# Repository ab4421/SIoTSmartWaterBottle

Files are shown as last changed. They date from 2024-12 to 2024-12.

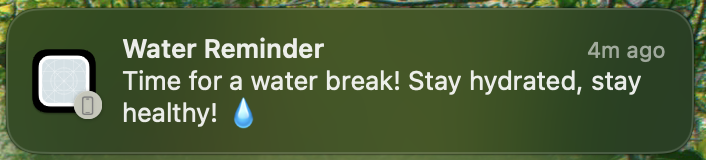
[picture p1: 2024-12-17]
AppFiles/AppScreenshots/WaterReminderNotification.png

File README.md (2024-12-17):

# Retrofit IoT Water Bottle Tracker

This repository contains the code and documentation for a compact, retrofit IoT device that transforms any conventional water bottle into a smart hydration tracker. By integrating a load cell, IMU, BLE communication, and HealthKit APIs, this system dynamically measures water volume, correlates intake with exercise data, and provides personalised daily hydration goals and reminders.

## License and Contributions
This project is licensed under the [Creative Commons Attribution-NonCommercial 4.0 International (CC BY-NC 4.0)](https://creativecommons.org/licenses/by-nc/4.0/) license.

**Key points:**
- **Attribution Required:** You must give appropriate credit to the original author(s) and clearly indicate any changes made.
- **Non-Commercial:** You may not use the material for commercial purposes.
- **No Additional Restrictions:** You may not apply legal terms or technological measures that legally restrict others from doing anything the license permits.

Contributions are welcome! Feel free to open issues, suggest features, or submit pull requests. 

**Acknowledgement:** Large Language Models (LLMs) such as ChatGPT (GPT-4), Sonnet 3.5, and related tools were used to assist with syntax, code snippet generation, and refining implementations. These tools helped streamline development, clarify code logic, and improve documentation quality.

## Key Features

- **External Sensing for Water Volume:**  
  Attaches to any bottle’s base. A load cell sensor and calibration logic convert weight into volume (1 g ≈ 1 mL).
  
- **IMU-Based Stability Checks:**  
  Uses an onboard 6-axis IMU to ensure accurate measurements only when the bottle is upright and stable.
  
- **BLE Connectivity:**  
  Communicates with an iOS application in real-time via Bluetooth Low Energy. Sensor data, state machine updates, and commands are all exchanged wirelessly.

- **HealthKit Integration:**  
  Dynamically adjusts daily hydration goals based on the user’s personal health metrics (height, weight, age) and exercise time sourced from Apple Watch via HealthKit.

- **User-Centred UI/UX:**  
  The accompanying iOS app displays daily intake progress, water levels, and allows manual entry of off-bottle consumption. Day/week data views and statistical insights help users understand and improve their hydration habits.

- **Actuation and Interventions:**  
  Sends notifications if no water intake is logged within an hour, prompting the user to drink or refill. On-board LED indicators reflect device states and assist in debugging.

## Repository Structure

- **/Arduino**  
  Contains Arduino/C++ source code for the SeeedStudio XIAO nrf52840 Sense board. This includes:
  - Load cell sensor calibration and reading code.
  - IMU data collection and stability logic.
  - BLE services and characteristics for data transmission.
  - State machine logic for IDLE → AWAKE → ACTIVE → REFILL states.
 - The final final code for the entire project is in BottleHousingv1.ino

- **/AppFiles**  
  Swift/SwiftUI code for the iOS application:
  - BLEManager implementation for scanning, connecting, and receiving data from the device.
  - Views for daily/weekly intake data, goal calculation, and user interactions.
  - Integration with HealthKit to fetch activity and body metrics.
  - Notification scheduling for hydration reminders.

- **/Housing**  
  CAD files and STL models of the custom 3D-printed housing designed to fit the sensor assembly onto various bottles.

- **/RawSensorDataPlots**  
  Sample CSV data (IMU and scale readings), calibration logs, and scripts/notebooks for offline data analysis and plotting.

- **/AppFiles/AppScreenshots**  
  All screenshots of app features and screens. 

## Getting Started

1. **Hardware Setup:**
   - Assemble the load cell (MUS) and connect it to the XIAO Sense board as per the wiring diagrams.
   - Modify the housing onto your chosen bottle, ensuring minimal interference and stable contact.
   
2. **Firmware Upload:**
   - Install the Arduino IDE and required board packages.
   - Open `ArduinoSketches/BottleHousingv1` in Arduino IDE.
   - Update any BLE UUIDs, gap values, or thresholds if needed.
   - Upload the code to the XIAO nrf52840 Sense board.

3. **iOS App Setup:**
   - Open `AppFiles/SmartWaterTracker` project in Xcode.
   - Connect an iOS device with BLE and HealthKit access.
   - Build and run the app on your device.
   - Grant necessary HealthKit permissions and pair with the IoT device.

4. **Calibration and Tuning:**
   - Use the app’s calibration function (tare) to set the empty bottle weight.
   - Perform test readings and compare to known reference weights to fine-tune the gap value if necessary.

## Dependencies and Requirements

- **Hardware:**
  - SeeedStudio XIAO nrf52840 Sense microcontroller.
  - M5Stack mini unit scale (MUS) or compatible load cell assembly.
  - BLE-compatible iOS device (iPhone/iPad running iOS 14+).
  
- **Software:**
  - Arduino IDE (v1.8.13 or newer).
  - Xcode (for iOS development).
  - Swift 5.0+ and iOS 14+ SDK.
  - HealthKit and Core Bluetooth frameworks.

## Contact and Support

For questions, issues, or support, please contact [ab4421@ic.ac.uk] or open an issue in this repository.

---
**Stay Hydrated!** This project aims to encourage healthier habits through unobtrusive IoT interventions and personalised guidance.

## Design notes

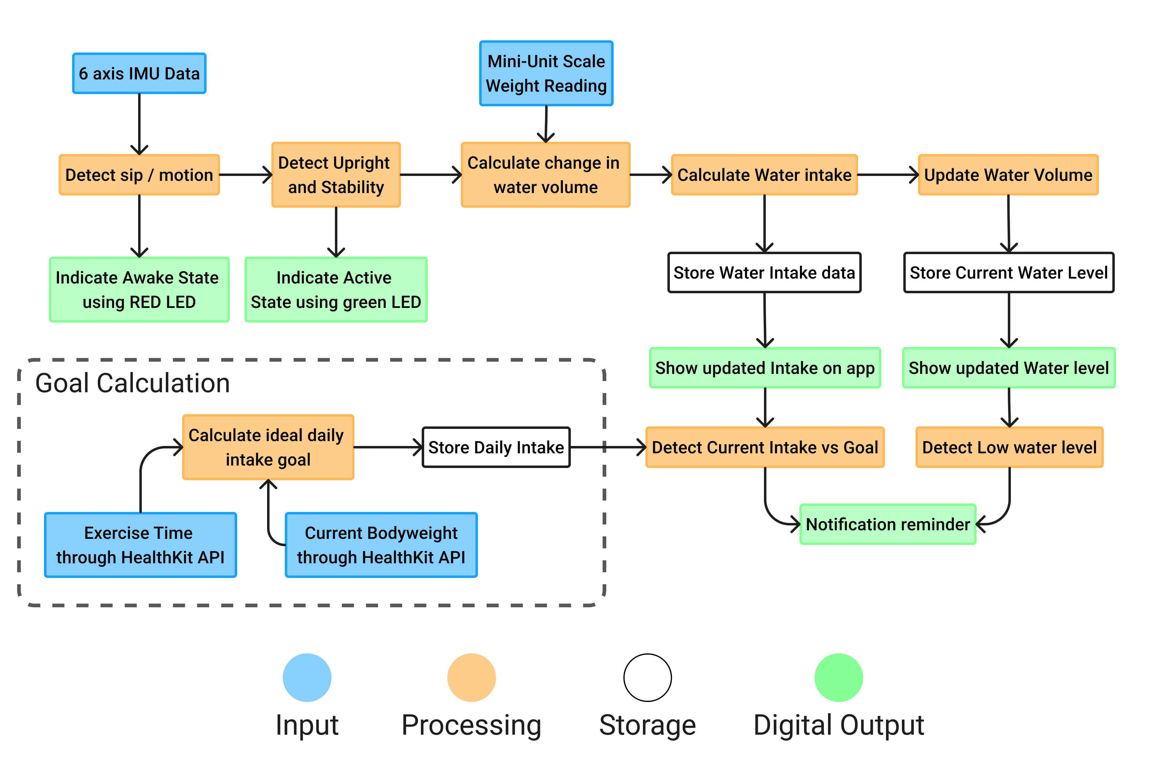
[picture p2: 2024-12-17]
SystemDiagram.png

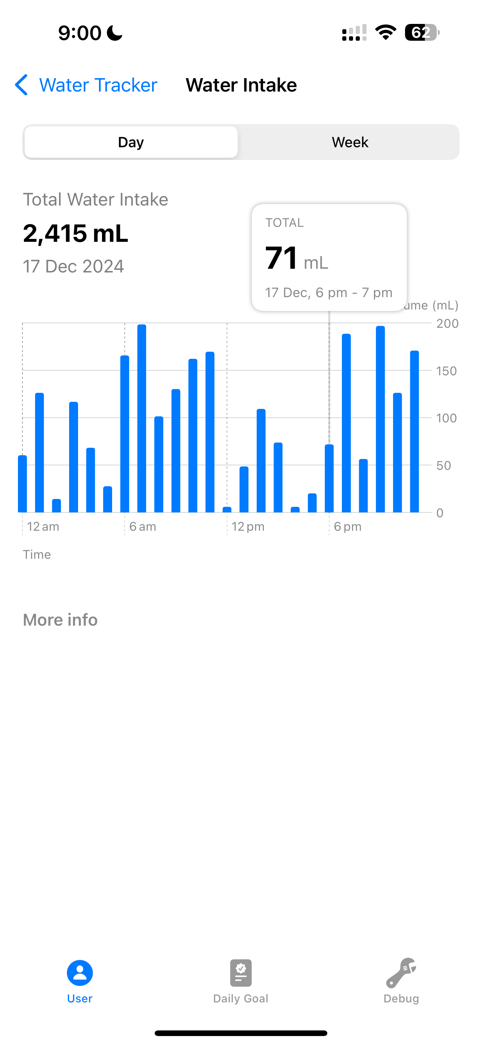
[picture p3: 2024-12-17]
AppFiles/AppScreenshots/DataViewDaily.PNG

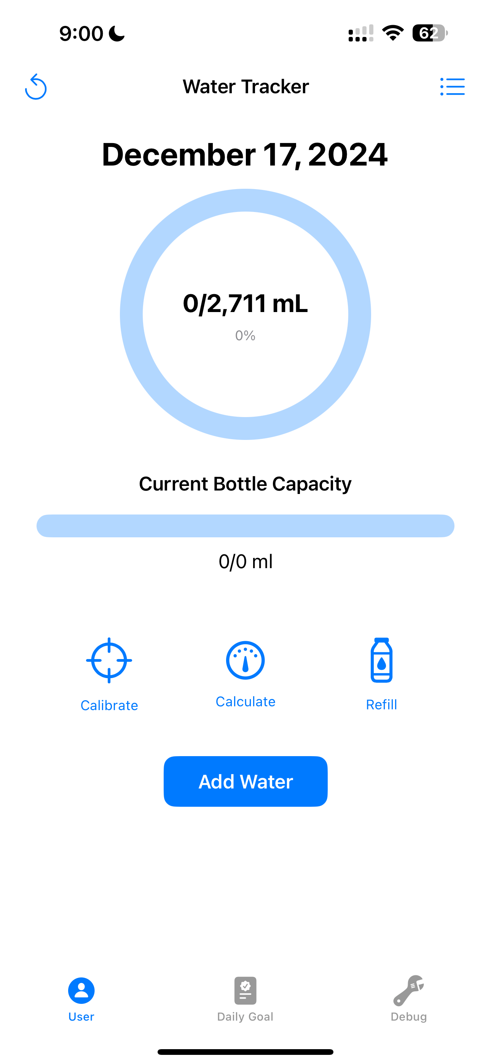
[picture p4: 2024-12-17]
AppFiles/AppScreenshots/UserView.PNG

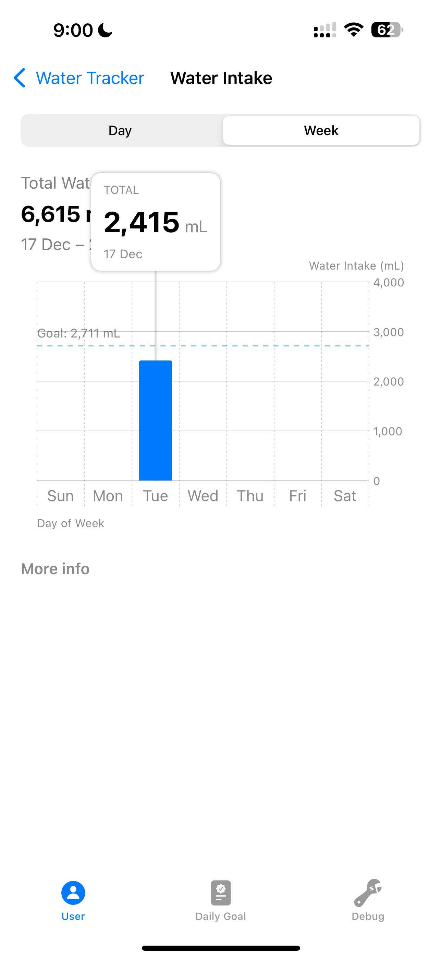
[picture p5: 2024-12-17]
AppFiles/AppScreenshots/DataViewWeekly.PNG

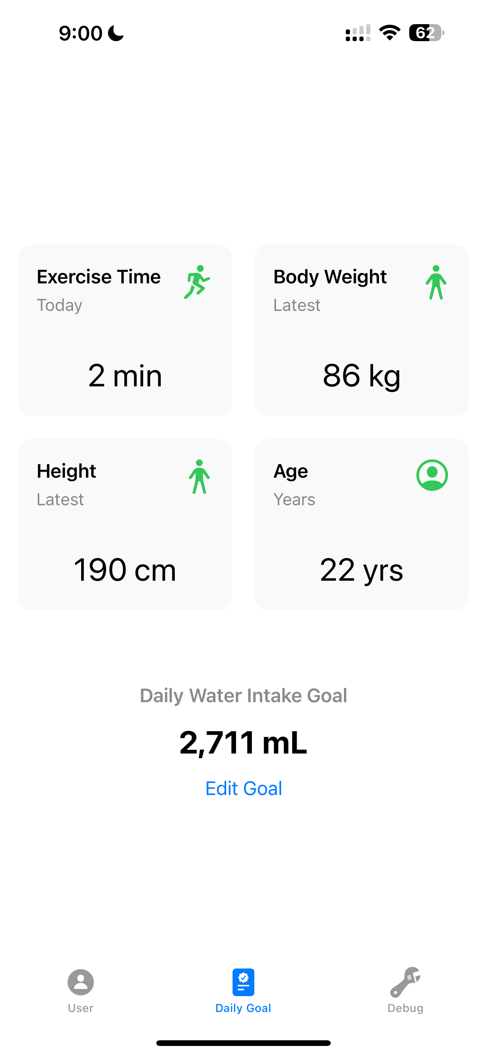
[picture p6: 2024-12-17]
AppFiles/AppScreenshots/GoalView.PNG

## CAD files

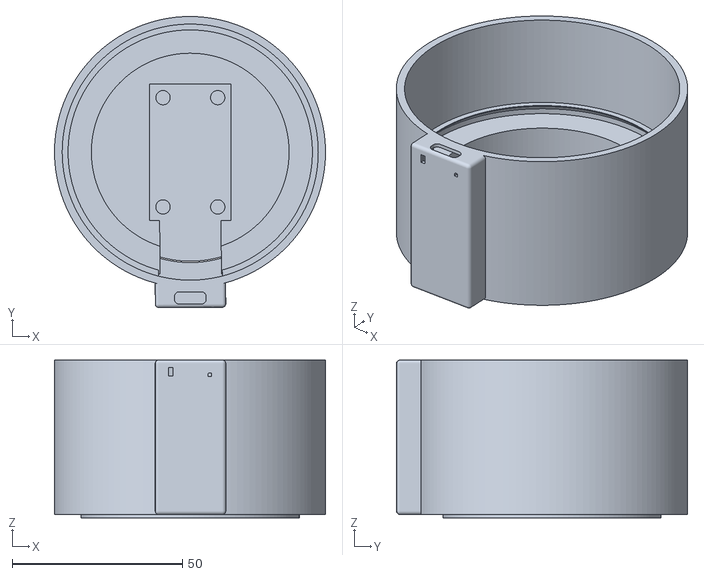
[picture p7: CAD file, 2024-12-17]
Housing/SIoTHousing3Dprint.stl
79.5 x 85.4 x 46.3

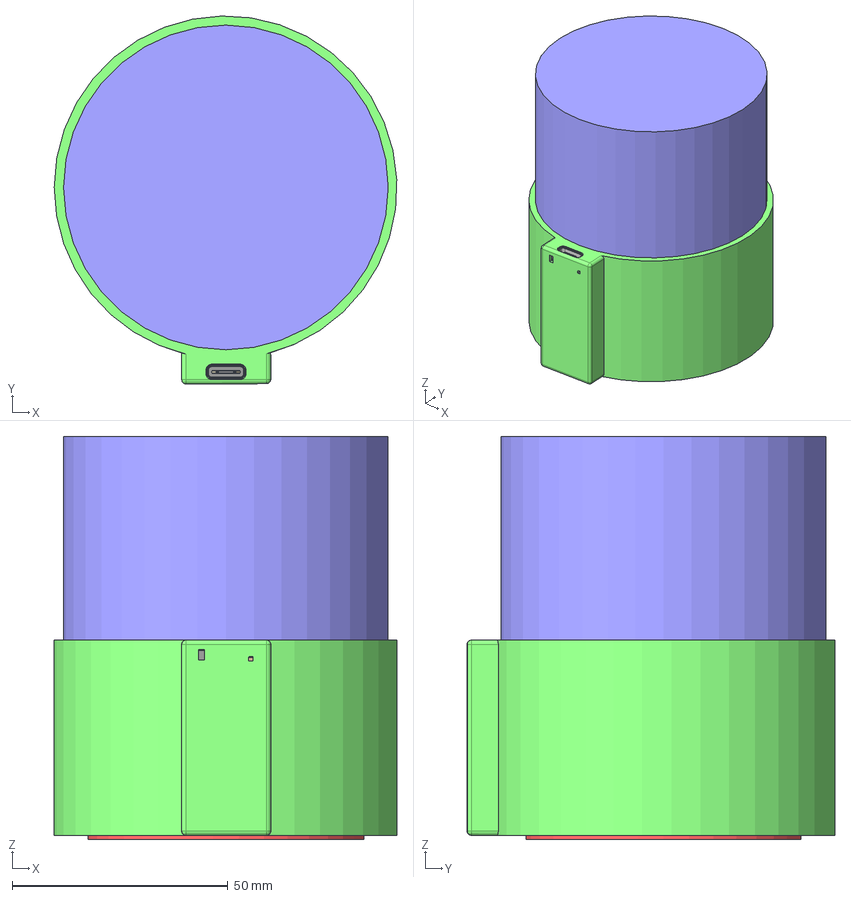
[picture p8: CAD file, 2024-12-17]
Housing/SIoTHousingModel.step
79.5 x 85.3 x 93.5 mm
Inner ring
BOSS-EXTRUDE14_8_:1
BOSS-EXTRUDE7_4_:1
BOSS-EXTRUDE7_3_:1
BOSS-EXTRUDE14_4_:1
BOSS-EXTRUDE14_2_:1
BOSS-EXTRUDE14_11_:1
BOSS-EXTRUDE7_7_:1
BOSS-EXTRUDE14_9_:1
BOSS-EXTRUDE14_3_:1
BOSS-EXTRUDE14_7_:1
MIRROR2:1
BOSS-EXTRUDE14_5_:1
BOSS-EXTRUDE14_12_:1
BOSS-EXTRUDE7_8_:1
BOSS-EXTRUDE7_1_:1
BOSS-EXTRUDE14_10_:1
BOSS-EXTRUDE7_9_:1
BOSS-EXTRUDE14_6_:1
BOSS-EXTRUDE14_1_:1
BOSS-EXTRUDE7_6_:1
BOSS-EXTRUDE7_2_:1
CUT-EXTRUDE5:1
BOSS-EXTRUDE7_5_:1
Shield:1
Pins:1
CAP:1
ANT1:1
Silkscreen:1
CAP:2
CAP 3:1
LED:1
USR:1
2 v1:1
Imported

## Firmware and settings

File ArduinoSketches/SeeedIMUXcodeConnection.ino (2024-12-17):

#include <Wire.h>
#include <ArduinoBLE.h>
#include "LSM6DS3.h"
#include "UNIT_SCALES.h"

// IMU and BLE configuration
LSM6DS3 myIMU(I2C_MODE, 0x6A); // I2C address for IMU
BLEService imuService("12345678-1234-5678-1234-56789abcdef0");
BLECharacteristic accelCharacteristic("12345678-1234-5678-1234-56789abcdef1", BLENotify, 20);
BLECharacteristic gyroCharacteristic("12345678-1234-5678-1234-56789abcdef2", BLENotify, 20);
BLECharacteristic scaleCharacteristic("12345678-1234-5678-1234-56789abcdef3", BLENotify, 20);
BLECharacteristic uprightCharacteristic("12345678-1234-5678-1234-56789abcdef4", BLENotify, 20);
BLECharacteristic calibrateCharacteristic("12345678-1234-5678-1234-56789abcdef5", BLEWrite, 1); // For calibration command

// Mini Scale configuration
UNIT_SCALES scales;
float gap = 183.3;  // Replace with your calibrated gap value

// State management
enum State {
    IDLE_STATE,
    AWAKE_STATE,
    ACTIVE_STATE
};

State currentState = IDLE_STATE;
unsigned long stateStartTime = 0;
unsigned long awakeTimeout = 30000;  // 30 seconds timeout for AWAKE_STATE

#define SIGNIFICANT_MOVEMENT_THRESHOLD 0.2  // Adjust as needed
#define STABILITY_THRESHOLD 0.02            // Adjust as needed
#define SIGNIFICANT_VOLUME_CHANGE 5.0       // in mL, adjust as needed

// Variables for IMU data
float accelX = 0, accelY = 0, accelZ = 0;
float gyroX = 0, gyroY = 0, gyroZ = 0;
float prevAccelX_move = 0, prevAccelY_move = 0, prevAccelZ_move = 0;
float prevAccelX_stable = 0, prevAccelY_stable = 0, prevAccelZ_stable = 0;

// Variables for volume tracking
float previousVolume = 0;

// Calibration flag
bool calibrationOccurred = false;

// Define LED pin mappings (using onboard LEDs)
#define LED_RED   LED_BUILTIN   // Red LED
#define LED_GREEN LED_GREEN  // Green LED
#define LED_BLUE  LED_BLUE   // Blue LED

void setup() {
    // Initialize serial communication
    Serial.begin(9600);
    //while (!Serial);

    // Initialize IMU
    if (myIMU.begin() != 0) {
        Serial.println("IMU initialization failed!");
        while (1);
    }
    Serial.println("IMU initialized successfully!");

    // Initialize BLE
    if (!BLE.begin()) {
        Serial.println("Starting BLE failed!");
        while (1);
    }
    BLE.setLocalName("Bottle Monitor");
    BLE.setAdvertisedService(imuService);

    imuService.addCharacteristic(accelCharacteristic);
    imuService.addCharacteristic(gyroCharacteristic);
    imuService.addCharacteristic(scaleCharacteristic);
    imuService.addCharacteristic(uprightCharacteristic);
    imuService.addCharacteristic(calibrateCharacteristic);

    BLE.addService(imuService);
    BLE.advertise();
    Serial.println("BLE IMU and Scale Peripheral is now advertising...");

    // Initialize Mini Scale
    Wire.begin();
    Wire.setClock(400000UL);

    while (!scales.begin(&Wire)) {
        Serial.println("Scales connect error");
        delay(1000);
    }

    scales.setLEDColor(0x001000);  // Optional: Set LED color on the scale unit
    scales.setGapValue(gap);
    Serial.println("Place the empty water bottle on the scale and press 'Calibrate' to zero the scale.");

    // Initialize LED pins as outputs
    pinMode(LED_RED, OUTPUT);
    pinMode(LED_GREEN, OUTPUT);
    pinMode(LED_BLUE, OUTPUT);

    // Turn off all LEDs initially
    digitalWrite(LED_RED, HIGH);    // HIGH turns the LED OFF
    digitalWrite(LED_GREEN, HIGH);
    digitalWrite(LED_BLUE, HIGH);
}

void loop() {
    // Check for BLE central connection
    BLEDevice central = BLE.central();
    if (central) {
        Serial.println("Connected to central");

        while (central.connected()) {
            // Handle calibration command in all states
            if (calibrateCharacteristic.written()) {
                uint8_t command = calibrateCharacteristic.value()[0];
                if (command == 1) {
                    scales.setOffset(); // Reset the Mini Scale
                    Serial.println("Mini Scale calibrated with empty bottle.");

                    // Set calibration flag
                    calibrationOccurred = true;

                    // Switch to ACTIVE_STATE to transmit reset value
                    currentState = ACTIVE_STATE;
                    stateStartTime = millis();
                }
            }

            // Get IMU readings
            accelX = myIMU.readFloatAccelX();
            accelY = myIMU.readFloatAccelY();
            accelZ = myIMU.readFloatAccelZ();
            gyroX = myIMU.readFloatGyroX();
            gyroY = myIMU.readFloatGyroY();
            gyroZ = myIMU.readFloatGyroZ();

            // Determine if the bottle is upright
            bool isUpright = abs(accelZ - 1.0) < 0.08; // Adjust threshold as needed
            String uprightStatus = isUpright ? "Upright" : "Not Upright";

            // Send accelerometer data
            char accelData[20];
            snprintf(accelData, sizeof(accelData), "%.2f,%.2f,%.2f", accelX, accelY, accelZ);
            accelCharacteristic.writeValue((const unsigned char *)accelData, strlen(accelData));

            // Send gyroscope data
            char gyroData[20];
            snprintf(gyroData, sizeof(gyroData), "%.2f,%.2f,%.2f", gyroX, gyroY, gyroZ);
            gyroCharacteristic.writeValue((const unsigned char *)gyroData, strlen(gyroData));

            // Send upright status to BLE characteristic
            char uprightData[20];
            snprintf(uprightData, sizeof(uprightData), "%s", uprightStatus.c_str());
            uprightCharacteristic.writeValue((const unsigned char *)uprightData, strlen(uprightData));

            // Now handle state-specific code
            switch (currentState) {
                case IDLE_STATE: {
                    // Turn on the Blue LED
                    digitalWrite(LED_RED, HIGH);
                    digitalWrite(LED_GREEN, HIGH);
                    digitalWrite(LED_BLUE, LOW); // LOW turns the LED ON

                    // Monitor movement
                    if (movementDetected()) {
                        Serial.println("Movement detected! Transitioning to AWAKE_STATE.");
                        currentState = AWAKE_STATE;
                        stateStartTime = millis();
                    }

                    break;
                }
                case AWAKE_STATE: {
                    // Turn on the Red LED
                    digitalWrite(LED_RED, LOW);
                    digitalWrite(LED_GREEN, HIGH);
                    digitalWrite(LED_BLUE, HIGH);

                    // Wait for bottle to stabilize and be upright
                    if (isBottleStable() && isUpright) {
                        Serial.println("Bottle is stable and upright! Transitioning to ACTIVE_STATE.");
                        currentState = ACTIVE_STATE;
                        stateStartTime = millis();
                    } else if (millis() - stateStartTime > awakeTimeout) {
                        Serial.println("Awake timeout reached. Returning to IDLE_STATE.");
                        currentState = IDLE_STATE;
                    }

                    break;
                }
                case ACTIVE_STATE: {
                    // Turn on the Green LED
                    digitalWrite(LED_RED, HIGH);
                    digitalWrite(LED_GREEN, LOW);
                    digitalWrite(LED_BLUE, HIGH);

                    // Take a reading from the Mini Scale
                    float weight = scales.getWeight();
                    float volume = weight;  // Assuming 1g = 1mL

                    // Debugging: Print previous and current volume
                    Serial.print("Previous Volume: "); Serial.println(previousVolume);
                    Serial.print("Current Volume: "); Serial.println(volume);

                    // Compare to previous value or if calibration occurred
                    if (abs(volume - previousVolume) >= SIGNIFICANT_VOLUME_CHANGE || calibrationOccurred) {
                        // Send water volume to app
                        char scaleData[20];
                        snprintf(scaleData, sizeof(scaleData), "%.2f mL", volume);
                        scaleCharacteristic.writeValue((const unsigned char *)scaleData, strlen(scaleData));

                        Serial.print("Water volume changed significantly or calibration occurred. New volume: ");
                        Serial.println(volume);

                        previousVolume = volume;

                        // Make the active state last 5 seconds
                        unsigned long activeStateStart = millis();
                        while (millis() - activeStateStart < 5000) {
                            // Keep sending the volume data to ensure the app receives it
                            scaleCharacteristic.writeValue((const unsigned char *)scaleData, strlen(scaleData));
                            delay(500);  // Send every 0.5 seconds
                        }

                        // Reset calibration flag
                        calibrationOccurred = false;

                        currentState = IDLE_STATE;
                        Serial.println("Returning to IDLE_STATE.");
                    } else {
                        // No significant change
                        Serial.println("No significant volume change. Returning to IDLE_STATE.");

                        // Reset calibration flag if it was set but no significant change occurred
                        calibrationOccurred = false;

                        currentState = IDLE_STATE;
                    }

                    break;
                }
                default: {
                    // Should not reach here
                    break;
                }
            }

            // Print values to serial monitor for debugging
            Serial.print("Current State: ");
            switch (currentState) {
                case IDLE_STATE:
                    Serial.println("IDLE_STATE");
                    break;
                case AWAKE_STATE:
                    Serial.println("AWAKE_STATE");
                    break;
                case ACTIVE_STATE:
                    Serial.println("ACTIVE_STATE");
                    break;
                default:
                    Serial.println("UNKNOWN_STATE");
                    break;
            }

            Serial.print("Accelerometer - X: "); Serial.print(accelX);
            Serial.print(", Y: "); Serial.print(accelY);
            Serial.print(", Z: "); Serial.println(accelZ);

            Serial.print("Gyroscope - X: "); Serial.print(gyroX);
            Serial.print(", Y: "); Serial.print(gyroY);
            Serial.print(", Z: "); Serial.println(gyroZ);

            Serial.print("Upright Status: "); Serial.println(uprightStatus);

            // Add previousVolume to the constantly updating serial output
            Serial.print("Previous Volume: "); Serial.println(previousVolume);

            Serial.println("---------------------------------------------------");

            delay(100);  // Short delay for loop iteration
        }

        Serial.println("Central disconnected");
    }
}

// Function to detect significant movement
bool movementDetected() {
    // Calculate the difference between current and previous accelerometer readings
    float deltaX = abs(accelX - prevAccelX_move);
    float deltaY = abs(accelY - prevAccelY_move);
    float deltaZ = abs(accelZ - prevAccelZ_move);

    // Update previous readings
    prevAccelX_move = accelX;
    prevAccelY_move = accelY;
    prevAccelZ_move = accelZ;

    // If any of the differences exceed the threshold, movement is detected
    if (deltaX > SIGNIFICANT_MOVEMENT_THRESHOLD || deltaY > SIGNIFICANT_MOVEMENT_THRESHOLD || deltaZ > SIGNIFICANT_MOVEMENT_THRESHOLD) {
        return true;
    } else {
        return false;
    }
}

// Function to check if the bottle is stable
bool isBottleStable() {
    // Calculate the difference between current and previous accelerometer readings
    float deltaX = abs(accelX - prevAccelX_stable);
    float deltaY = abs(accelY - prevAccelY_stable);
    float deltaZ = abs(accelZ - prevAccelZ_stable);

    // Update previous readings
    prevAccelX_stable = accelX;
    prevAccelY_stable = accelY;
    prevAccelZ_stable = accelZ;

    // If all differences are below the stability threshold, consider bottle stable
    if (deltaX < STABILITY_THRESHOLD && deltaY < STABILITY_THRESHOLD && deltaZ < STABILITY_THRESHOLD) {
        return true;
    } else {
        return false;
    }
}

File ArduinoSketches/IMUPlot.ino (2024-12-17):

#include <Wire.h>
#include "LSM6DS3.h"

// IMU configuration
LSM6DS3 myIMU(I2C_MODE, 0x6A); // I2C address for IMU
unsigned long startTime;

void setup() {
  Serial.begin(9600);
  while(!Serial);

  if (myIMU.begin() != 0) {
    Serial.println("IMU init failed");
    while (1);
  }

  Serial.println("timestamp(ms),accelX,accelY,accelZ,gyroX,gyroY,gyroZ");
  startTime = millis();
}

void loop() {
  float accelX = myIMU.readFloatAccelX();
  float accelY = myIMU.readFloatAccelY();
  float accelZ = myIMU.readFloatAccelZ();
  float gyroX  = myIMU.readFloatGyroX();
  float gyroY  = myIMU.readFloatGyroY();
  float gyroZ  = myIMU.readFloatGyroZ();

  unsigned long currentTime = millis() - startTime;

  // Print in CSV format:
  // timestamp, accelX, accelY, accelZ, gyroX, gyroY, gyroZ
  Serial.print(currentTime);
  Serial.print(",");
  Serial.print(accelX, 6);
  Serial.print(",");
  Serial.print(accelY, 6);
  Serial.print(",");
  Serial.print(accelZ, 6);
  Serial.print(",");
  Serial.print(gyroX, 6);
  Serial.print(",");
  Serial.print(gyroY, 6);
  Serial.print(",");
  Serial.println(gyroZ, 6);

  delay(100); // Adjust as needed for sampling rate
}

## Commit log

2024-12-17 Add files via upload
    Sketch to test IMU and Scale Functionality using the SeeedStudio
2024-12-17 housing folder
    [SIoTHousingModel.step]
